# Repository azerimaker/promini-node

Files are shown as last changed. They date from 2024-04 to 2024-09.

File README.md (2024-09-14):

# ProMini LoRaWAN Node
A LoRaWAN node based on the Arduino ProMini and the RFM95 LoRa module. Based on the original design by [Doug Larue](https://github.com/dlarue/KiCAD/tree/master/ProMini-LoRaWAN-node), but with some additional options:

* u.FL antenna connector
* Grove connector for I2C (can also be used for analog or digital signals)
* Voltage divider circuitry to measure battery voltage
* Added silkscreen labels
* Improved layout

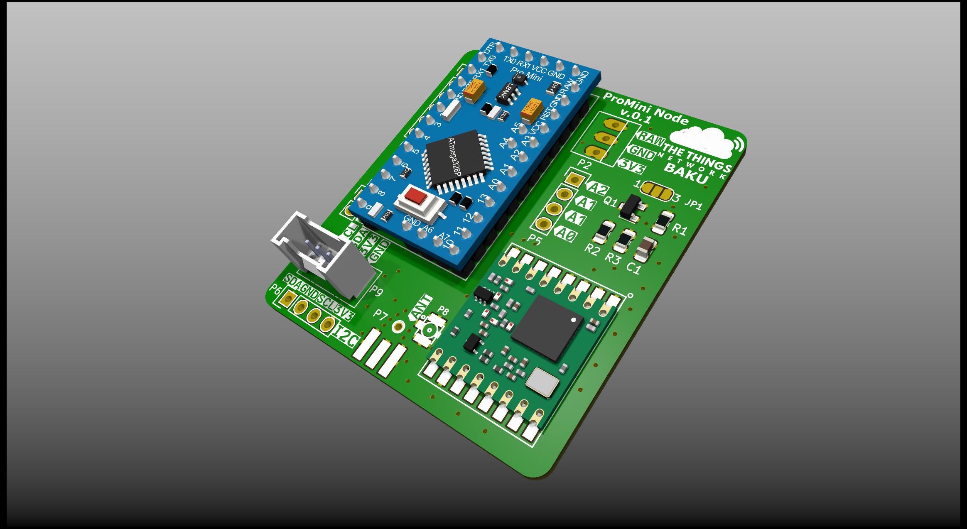
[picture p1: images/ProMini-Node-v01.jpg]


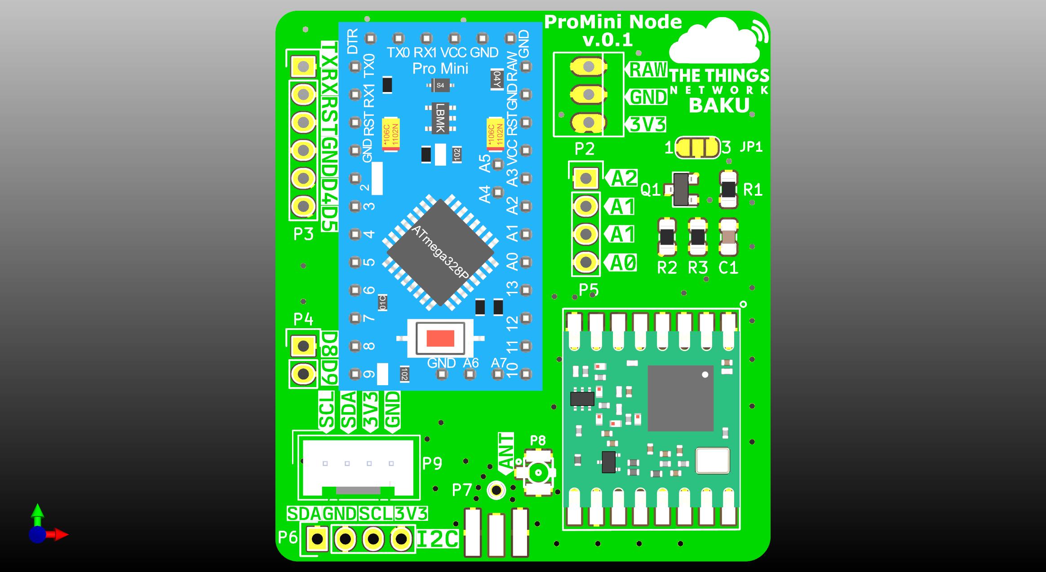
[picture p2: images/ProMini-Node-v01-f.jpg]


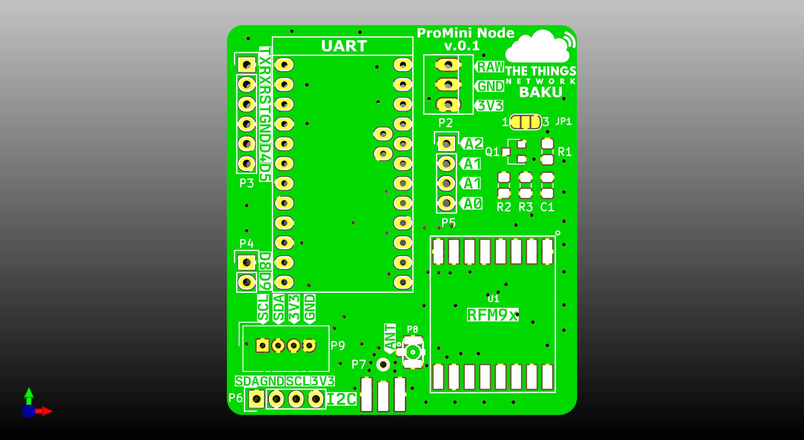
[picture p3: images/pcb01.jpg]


## Parts
* Arduino Pro Mini 3.3V, 8 Mhz
* RFM95W LoRa SX1276 module (frequency band based on your location preference, default EU868 MHz)
* Pin headers
* 4P Grove connector
* BSS84P P-Channel Mosfet Transistor SOT-23 SMD
* 0805 SMD Resistors and Capacitors (2x100K, 1x470K, 1x100nF)
* Wire-antenna of correct length (86mm for EU868) or edge-mounted SMA connector (e.g. [this part](https://www.digikey.com/product-detail/en/rf-solutions/CON-SMA-EDGE-S/CON-SMA-EDGE-S-ND/5845767)) or 

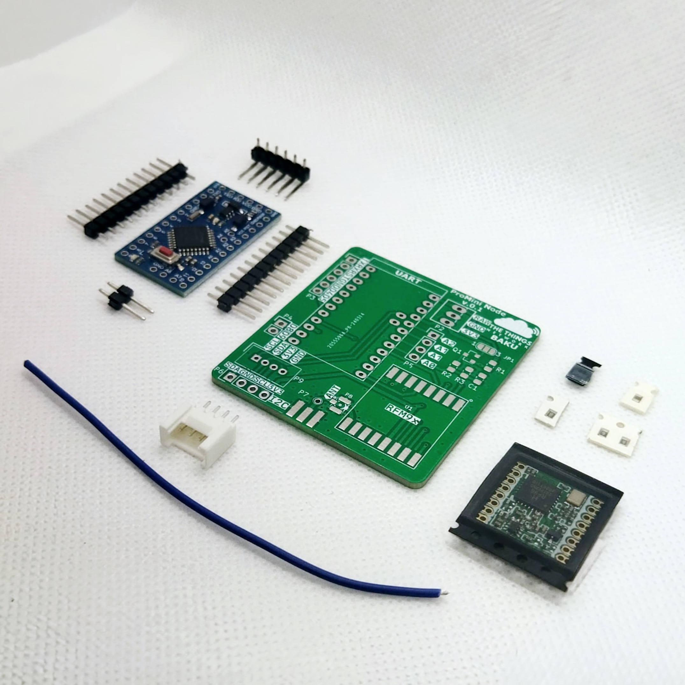
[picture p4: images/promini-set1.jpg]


## Additional information
* Board can be powered directly from 2 AA batteries to the 3.3V input or up to 10V on the RAW input pin
* Use this modified [LoRaWAN stack](https://github.com/azerimaker/arduino-lmic) for low memory footprint
* Online [interactive BOM viewer](https://htmlpreview.github.io/?https://github.com/azerimaker/promini-node/blob/master/hardware/bom/ibom.html)
* [Tutorial using this board by Frank Beks](https://www.thethingsnetwork.org/labs/story/creating-a-ttn-node)

## License
* Licensed under Creative Commons Attribution-ShareAlike 4.0 Unported License (CC BY-SA 4.0)
* Original work by [Doug Larue](https://github.com/dlarue)
* Modifications by [Severin Schols](https://github.com/tiefpunkt)
* Further modifications by [Orkhan Amiraslan](https://github.com/azerimaker)

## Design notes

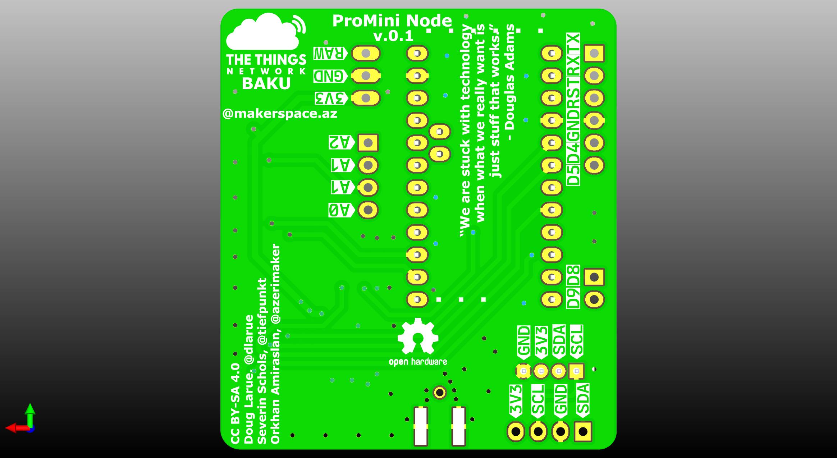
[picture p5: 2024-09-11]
images/ProMini-Node-v01-b.jpg

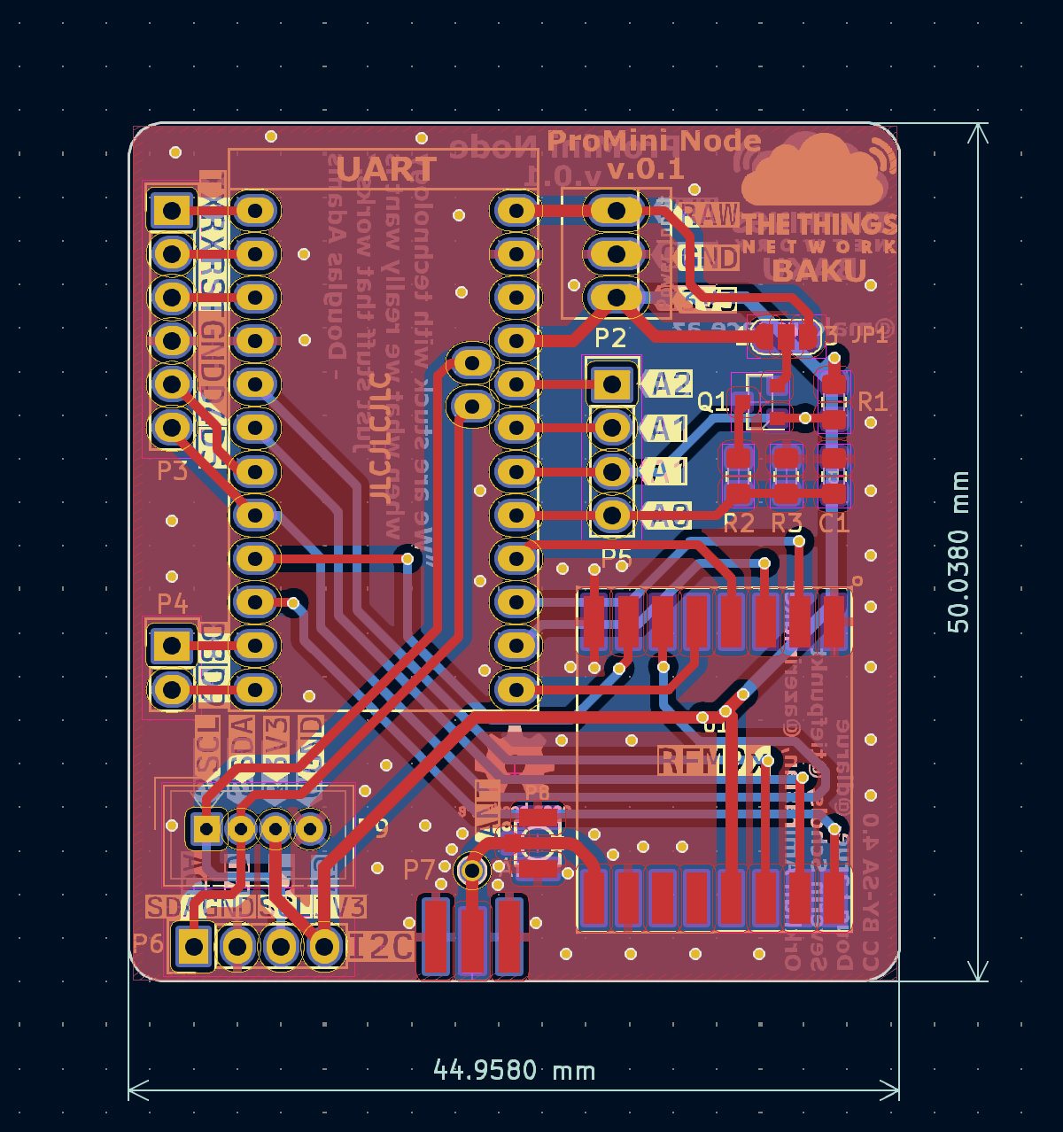
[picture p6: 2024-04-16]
images/pcb02.png

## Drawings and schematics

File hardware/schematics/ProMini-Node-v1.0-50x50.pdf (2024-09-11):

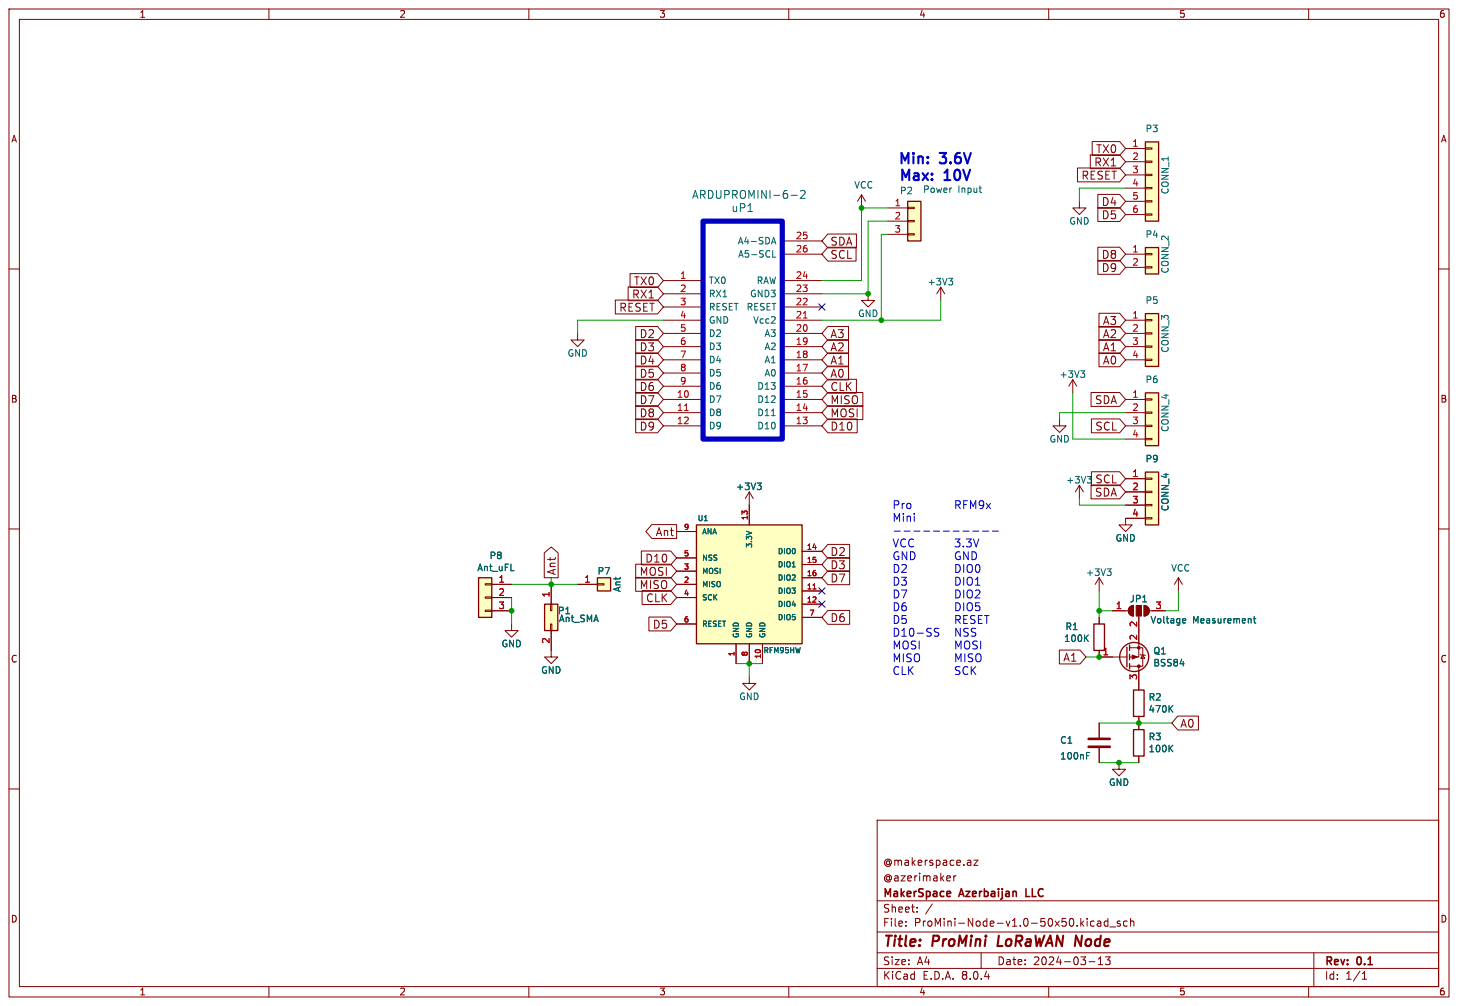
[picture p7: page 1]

Pro RFM9x Mini ----------- VCC 3.3V GND GND

Id: 1/1 Title: ProMini LoRaWAN Node

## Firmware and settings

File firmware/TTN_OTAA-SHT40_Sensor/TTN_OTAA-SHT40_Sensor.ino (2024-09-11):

/*******************************************************************************
 * Copyright (c) 2015 Thomas Telkamp and Matthijs Kooijman
 * Copyright (c) 2024 Orkhan Amiraslan @azerimaker - Makerspace Azeraijan LLC @makerspace.az
 *
 * Used Arduino Pro Mini ATmega328P 3.3V 8 MHz dev-board + RFM95W module -> https://github.com/azerimaker/promini-node
 * Used sensor module -> https://makerstore.az/product/sht40-temp-humidity-sensor-module-mt-labs/
 *
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
 * This example sends a valid LoRaWAN packet with payload "Hello,
 * world!", using frequency and encryption settings matching those of
 * the The Things Network.
 *
 * This uses OTAA (Over-the-air activation), where where a DevEUI and
 * application key is configured, which are used in an over-the-air
 * activation procedure where a DevAddr and session keys are
 * assigned/generated for use with all further communication.
 *
 * Note: LoRaWAN per sub-band duty-cycle limitation is enforced (1% in
 * g1, 0.1% in g2), but not the TTN fair usage policy (which is probably
 * violated by this sketch when left running for longer)!

 * To use this sketch, first register your application and device with
 * the things network, to set or generate an AppEUI, DevEUI and AppKey.
 * Multiple devices can use the same AppEUI, but each device has its own
 * DevEUI and AppKey.
 *
 * Do not forget to define the radio type correctly in config.h.
 *
 *******************************************************************************
 * TTN Payload formatter:

 function decodeUplink(input) {
  var data = {};
  data.temperature = ((input.bytes[0] << 8) + input.bytes[1])/100;
  data.humidity = ((input.bytes[2] << 8) + input.bytes[3])/100;

  return {
    data: data,
  };
}
 
  *******************************************************************************
 */

#include <lmic.h> // https://github.com/azerimaker/arduino-lmic
#include <hal/hal.h>
#include <SPI.h>
#include <Adafruit_SHT4x.h> // https://github.com/adafruit/Adafruit_SHT4x

// This EUI must be in little-endian format, so least-significant-byte
// first. When copying an EUI from ttnctl output, this means to reverse
// the bytes. For TTN issued EUIs the last bytes should be 0xD5, 0xB3,0x70.
static const u1_t PROGMEM APPEUI[8]={ 0x00, 0x00, 0x00, 0x00, 0x00, 0x00, 0x00, 0x00 }; // LSB -  little endian format
static const u1_t PROGMEM DEVEUI[8]={ 0x00, 0x00, 0x00, 0x00, 0x00, 0x00, 0x00, 0x00 }; // LSB -  little endian format
// This key should be in big endian format (or, since it is not really a
// number but a block of memory, endianness does not really apply). In
// practice, a key taken from ttnctl can be copied as-is.
// The key shown here is the semtech default key.
static const u1_t PROGMEM APPKEY[16] = { 0x00, 0x00, 0x00, 0x00, 0x00, 0x00, 0x00, 0x00, 0x00, 0x00, 0x00, 0x00, 0x00, 0x00, 0x00, 0x00 };

void os_getArtEui (u1_t* buf) { memcpy_P(buf, APPEUI, 8);}
void os_getDevEui (u1_t* buf) { memcpy_P(buf, DEVEUI, 8);}
void os_getDevKey (u1_t* buf) { memcpy_P(buf, APPKEY, 16);}

Adafruit_SHT4x sht40;
// Variables to store sensor data
float temperature = 0;
float humidity = 0;

static uint8_t payload[4]; // 4 byte packet size
static osjob_t sendjob;

const unsigned TX_INTERVAL = 30; // Schedule TX every this many seconds

// Pin mapping
const lmic_pinmap lmic_pins = {
    .nss = 10,                  // NSS
    .rxtx = LMIC_UNUSED_PIN,
    .rst = 5,                   // RESET
    .dio = {2, 3, 7},           // DIO0, DIO1, DIO2
};

void onEvent (ev_t ev) {
    Serial.print(os_getTime());
    Serial.print(": ");
    switch(ev) {
        case EV_SCAN_TIMEOUT:
            Serial.println(F("EV_SCAN_TIMEOUT"));
            break;
        case EV_BEACON_FOUND:
            Serial.println(F("EV_BEACON_FOUND"));
            break;
        case EV_BEACON_MISSED:
            Serial.println(F("EV_BEACON_MISSED"));
            break;
        case EV_BEACON_TRACKED:
            Serial.println(F("EV_BEACON_TRACKED"));
            break;
        case EV_JOINING:
            Serial.println(F("EV_JOINING"));
            break;
        case EV_JOINED:
            Serial.println(F("EV_JOINED"));

            // Disable link check validation (automatically enabled
            // during join, but not supported by TTN at this time).
            LMIC_setLinkCheckMode(0);
            break;
        case EV_RFU1:
            Serial.println(F("EV_RFU1"));
            break;
        case EV_JOIN_FAILED:
            Serial.println(F("EV_JOIN_FAILED"));
            break;
        case EV_REJOIN_FAILED:
            Serial.println(F("EV_REJOIN_FAILED"));
            break;
            break;
        case EV_TXCOMPLETE:
            Serial.println(F("EV_TXCOMPLETE (includes waiting for RX windows)"));
            if (LMIC.txrxFlags & TXRX_ACK)
              Serial.println(F("Received ack"));
            if (LMIC.dataLen) {
              Serial.println(F("Received "));
              Serial.println(LMIC.dataLen);
              Serial.println(F(" bytes of payload"));
            }
            // Schedule next transmission
            os_setTimedCallback(&sendjob, os_getTime()+sec2osticks(TX_INTERVAL), do_send);
            break;
        case EV_LOST_TSYNC:
            Serial.println(F("EV_LOST_TSYNC"));
            break;
        case EV_RESET:
            Serial.println(F("EV_RESET"));
            break;
        case EV_RXCOMPLETE:
            // data received in ping slot
            Serial.println(F("EV_RXCOMPLETE"));
            break;
        case EV_LINK_DEAD:
            Serial.println(F("EV_LINK_DEAD"));
            break;
        case EV_LINK_ALIVE:
            Serial.println(F("EV_LINK_ALIVE"));
            break;
         default:
            Serial.println(F("Unknown event"));
            break;
    }
}

void do_send(osjob_t* j){

    // Read the SHT40 sensor
    sensors_event_t temp_event, humidity_event;
    sht40.getEvent(&humidity_event, &temp_event);

    temperature = temp_event.temperature;
    humidity = humidity_event.relative_humidity;

    Serial.print(F("Temperature: ")); 
    Serial.print(temperature);
    Serial.print(F(" C, Humidity: "));
    Serial.print(humidity);
    Serial.println(F("% RH"));

    // Convert temperature and humidity to bytes
    int16_t temp_int = (int16_t)(temperature * 100); // Multiply by 100 to keep two decimal places
    int16_t hum_int = (int16_t)(humidity * 100);     // Multiply by 100 for the same reason

    payload[0] = temp_int >> 8;
    payload[1] = temp_int & 0xFF;
    payload[2] = hum_int >> 8;
    payload[3] = hum_int & 0xFF;

    /* // Alternative code
    payload[0] = highByte(temp_int);
    payload[1] = lowByte(temp_int);
    payload[2] = highByte(hum_int);
    payload[3] = lowByte(hum_int); 
    */

    // Check if there is not a current TX/RX job running
    if (LMIC.opmode & OP_TXRXPEND) {
        Serial.println(F("OP_TXRXPEND, not sending"));
    } else {
        // Prepare upstream data transmission at the next possible time.
        LMIC_setTxData2(1, payload, sizeof(payload), 0);
        //LMIC_setTxData2(1, payload, sizeof(payload), 0);
        Serial.println(F("Packet queued"));
    }
    // Next TX is scheduled after TX_COMPLETE event.
}

void setup() {
    Serial.begin(9600);
    Serial.println(F("Starting"));

    // Initialize the SHT40 sensor
    if (!sht40.begin()) {
        Serial.println(F("Couldn't find SHT40 sensor!"));
        while (1);
    }
    Serial.println(F("Found SHT40 sensor"));
    Serial.print(F("Serial number 0x"));
    Serial.println(sht40.readSerial(), HEX);

    // You can have 3 different precisions, higher precision takes longer
  sht40.setPrecision(SHT4X_HIGH_PRECISION);  // <--modify here
  switch (sht40.getPrecision()) {
     case SHT4X_HIGH_PRECISION: 
       Serial.println(F("High precision"));
       break;
     case SHT4X_MED_PRECISION: 
       Serial.println(F("Med precision"));
       break;
     case SHT4X_LOW_PRECISION: 
       Serial.println(F("Low precision"));
       break;
  }

  // You can have 6 different heater settings
  // higher heat and longer times uses more power
  // and reads will take longer too!
  sht40.setHeater(SHT4X_NO_HEATER); // <--modify here
  switch (sht40.getHeater()) {
     case SHT4X_NO_HEATER: 
       Serial.println(F("No heater"));
       break;
     case SHT4X_HIGH_HEATER_1S: 
       Serial.println(F("High heat for 1 second"));
       break;
     case SHT4X_HIGH_HEATER_100MS: 
       Serial.println(F("High heat for 0.1 second"));
       break;
     case SHT4X_MED_HEATER_1S: 
       Serial.println(F("Medium heat for 1 second"));
       break;
     case SHT4X_MED_HEATER_100MS: 
       Serial.println(F("Medium heat for 0.1 second"));
       break;
     case SHT4X_LOW_HEATER_1S: 
       Serial.println(F("Low heat for 1 second"));
       break;
     case SHT4X_LOW_HEATER_100MS: 
       Serial.println(F("Low heat for 0.1 second"));
       break;
  }

    // LMIC init
    os_init();
    // Reset the MAC state. Session and pending data transfers will be discarded.
    LMIC_reset();

    // Use with Arduino Pro Mini ATmega328P 3.3V 8 MHz
    // Let LMIC compensate for +/- 1% clock error
    LMIC_setClockError(MAX_CLOCK_ERROR * 1 / 100); 

    // Start job (sending automatically starts OTAA too)
    do_send(&sendjob);
}

void loop() {
    os_runloop_once();
}

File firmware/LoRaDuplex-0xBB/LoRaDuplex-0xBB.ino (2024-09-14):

/*
  LoRa Duplex - Rx-Tx communication

  Sends a message every half second, and polls continually
  for new incoming messages. Implements a one-byte addressing scheme,
  with 0xFF as the broadcast address.

  Uses readString() from Stream class to read payload. The Stream class'
  timeout may affect other functuons, like the radio's callback. For an

  created 28 April 2017 by Tom Igoe
  created 18 April 2024 by Orkhan Amiraslan
*/


#include <SPI.h>              // include libraries
#include <LoRa.h>             // https://github.com/sandeepmistry/arduino-LoRa

const int csPin = 10;         // LoRa radio chip select
const int resetPin = 5;       // LoRa radio reset
const int irqPin = 2;         // change for your board; must be a hardware interrupt pin, D2 INT0, D3 INT1

String outgoing;              // outgoing message

byte msgCount = 0;            // count of outgoing messages
byte localAddress = 0xBB;     // address of this device
byte destination = 0xFF;      // destination to send to

long lastSendTime = 0;        // last send time
int interval = 2000;          // interval between sends

void setup() {
  Serial.begin(9600);                   // initialize serial
  while (!Serial);

  Serial.println("LoRa Duplex");

  // override the default CS, reset, and IRQ pins (optional)
  LoRa.setPins(csPin, resetPin, irqPin);// set CS, reset, IRQ pin

  if (!LoRa.begin(868E6)) {             // initialize ratio at 868 MHz
    Serial.println("LoRa init failed. Check your connections.");
    while (true);                       // if failed, do nothing
  }

  Serial.println("LoRa init succeeded.");
}

void loop() {
  if (millis() - lastSendTime > interval) {
    String message = "HeLoRa World from Node 2!";   // send a message
    sendMessage(message);
    Serial.println("Sending " + message);
    lastSendTime = millis();            // timestamp the message
    interval = random(2000) + 1000;    // 2-3 seconds
  }

  // parse for a packet, and call onReceive with the result:
  onReceive(LoRa.parsePacket());
}

void sendMessage(String outgoing) {
  LoRa.beginPacket();                   // start packet
  LoRa.write(destination);              // add destination address
  LoRa.write(localAddress);             // add sender address
  LoRa.write(msgCount);                 // add message ID
  LoRa.write(outgoing.length());        // add payload length
  LoRa.print(outgoing);                 // add payload
  LoRa.endPacket();                     // finish packet and send it
  msgCount++;                           // increment message ID
}

void onReceive(int packetSize) {
  if (packetSize == 0) return;          // if there's no packet, return

  // read packet header bytes:
  int recipient = LoRa.read();          // recipient address, change this for every device
  byte sender = LoRa.read();            // sender address, change this for every device
  byte incomingMsgId = LoRa.read();     // incoming msg ID
  byte incomingLength = LoRa.read();    // incoming msg length

  String incoming = "";

  while (LoRa.available()) {
    incoming += (char)LoRa.read();
  }

  if (incomingLength != incoming.length()) {   // check length for error
    Serial.println("error: message length does not match length");
    return;                             // skip rest of function
  }

  // if the recipient isn't this device or broadcast,
  if (recipient != localAddress && recipient != 0xFF) {
    Serial.println("This message is not for me.");
    return;                             // skip rest of function
  }

  // if message is for this device, or broadcast, print details:
  Serial.println("Received from: 0x" + String(sender, HEX));
  Serial.println("Sent to: 0x" + String(recipient, HEX));
  Serial.println("Message ID: " + String(incomingMsgId));
  Serial.println("Message length: " + String(incomingLength));
  Serial.println("Message: " + incoming);
  Serial.println("RSSI: " + String(LoRa.packetRssi()));
  Serial.println("Snr: " + String(LoRa.packetSnr()));
  Serial.println();
}

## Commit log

2024-03-13 pcb v.0.1
    TTN Baku version
    [ProMini-Node-v1.0-50x50.kicad_pcb, ProMini-Node-v1.0-50x50.kicad_sch, ProMini-Node-v1.0-50x50.sch]
2024-04-16 hw: PCB renders added
    [ProMini-Node-v1.0-50x50.kicad_pcb]
2024-04-17 docs: Image update
    [ProMini-Node-v1.0-50x50.kicad_pcb]
2024-04-20 fw examples
    [ProMini-Node-v1.0-50x50.kicad_sch]
2024-09-10 Sch update
    [ProMini-Node-v1.0-50x50.kicad_sch]
2024-09-11 Update renders, added BOM
    [ProMini-Node-v1.0-50x50.kicad_pcb]
2024-09-11 example firmware update
    [ProMini-Node-v1.0-50x50.kicad_pcb, ProMini-Node-v1.0-50x50.kicad_sch]
2024-09-15 Small fixes
    [ProMini-Node-v1.0-50x50.kicad_sch]
